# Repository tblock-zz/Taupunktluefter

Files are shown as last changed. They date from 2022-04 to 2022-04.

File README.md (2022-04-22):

Dies ist meine vereinfachte Version vom Taupunktlüfter der Maker Media GmbH.
Das Original mit den wichtigsten Fragen rund um den Taupunktlüfter beantwortet eine **[FAQ](https://heise.de/-6526328)**. Die vollständigen Artikel zum Projekt gibt es in der **[Make-Ausgabe 1/22 ab Seite 22](https://www.heise.de/select/make/2022/1/2135511212557842576)** und in der **[Make-Ausgabe 2/22 ab Seite 82](https://www.heise.de/select/make/2022/2/2204711461516715363)** zu lesen.

Das Original Github Projekt liegt hier: https://github.com/MakeMagazinDE/Taupunktluefter

# Taupunktlüfter

Der Zweig vom Original ist bewusst absolut einfach gehalten. Er besitzt nur noch eine vereinfachte Anzeige mit 2 LEDs. Rot für Fehler und grün für ordnungsgemäßen Betrieb. 

Allerdings habe ich die C++ Datei verändert. Einmal wird ein gleitender Mittelwert aus der Temperatur und der Luftfeuchtigkeit gebildet mit einer Probe alle 1s. 
Nach 5s wird dann die Taupunktberechnung ausgeführt und entsprechend das Relais geschaltet.

Der Code befindet sich im Verzeichnis TaupunktLueftungEinfach
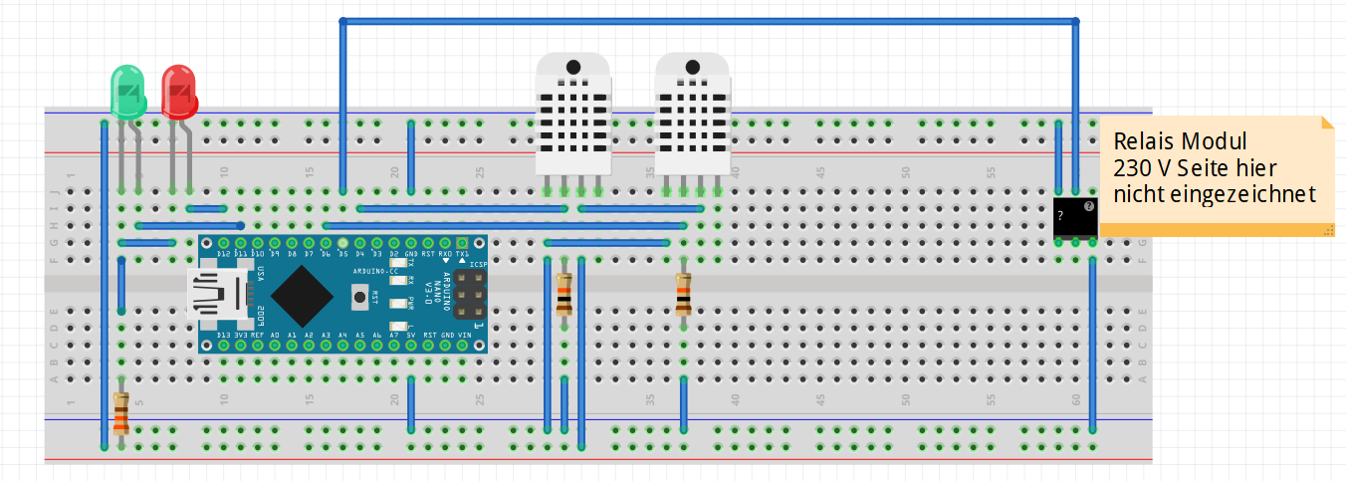
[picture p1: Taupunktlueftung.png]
Taupunktluefter

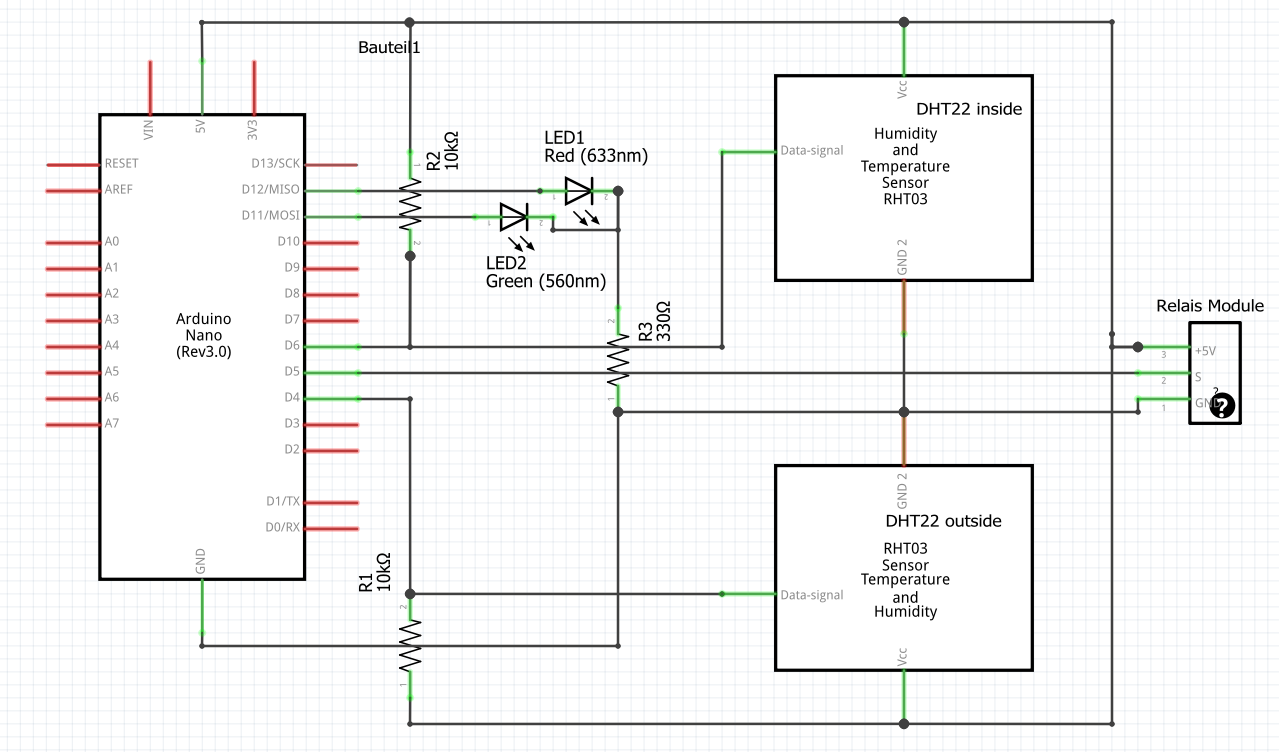
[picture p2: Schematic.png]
Schaltplan


Teileliste:
- 2 x Widerstand 10 kOhm
- 1 x Widerstand 330 Ohm
- 2 x DHT22
- 1 x Leuchtdiode rot
- 1 x Leuchtdiode grün
- 1 x Arduino Nano oder Arduino Uno etc.
- 1 x Relaismodul mit 5V Ansteuerung
- 1 x Lüfter 230 V

Im Programm werden die Bibliotheken DHT sensor library von Adafruit und Sodaq_wdt verwendet.

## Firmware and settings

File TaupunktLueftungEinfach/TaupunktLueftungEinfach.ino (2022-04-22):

/*
This code is without any warranty and without any liability of any kind.
Be aware that the FAN may use high voltage and it is your responsibility to understand that wrong usage may damage 
your life or your property.
*/
// These three libraries are necessary:
#include "DHT.h"       // DHT sensor library from Adafruit
#include <Wire.h> 
#include <avr/wdt.h>

//-------------------------------------------------------------------------------------------------------
#define PIN_RELAIS          5 // air venting relais control pin
#define PIN_DHT1            6 // data line inner DHT sensor
#define PIN_DHT2            4 // data line outer DHT sensor
#define PIN_LED_OK         11
#define PIN_LED_ERR        12

#define RELAIS_ON        HIGH
#define RELAIS_OFF        LOW

#define CORRECTION_T_1  -3.0f // correction value for inner temperature
#define CORRECTION_T_2  -4.0f // correction value for outer temperature
#define CORRECTION_H_1   0.0f // correction value for inner humidity
#define CORRECTION_H_2   0.0f // correction value for outer humidity

#define MIN_DEW          5.0f // minimal dew point difference for switching the relais
#define HYSTERESIS       1.0f // Distence for relais on/off switching
#define MIN_TEMP_1      14.0f // minimal inner temperature for activating the venting
#define MIN_TEMP_2     -10.0f // minimal outer temperature for activating the venting
//-------------------------------------------------------------------------------------------------------
typedef struct {
    float tmprt;              // temperatur
    float hmdty;              // humidity
} tData;

typedef struct {
    tData avrg;
    tData crctn;              // correction values
    float dp;                 // dew point
    DHT* pDht;                // pointer to the sensor object
} tFiltered;
//-------------------------------------------------------------------------------------------------------

DHT dht1(PIN_DHT1, DHT22);    // the inner sensor
DHT dht2(PIN_DHT2, DHT22);    // the outer sensor
tFiltered data[2];            // the data structure for the values for inner and outer sensor
bool relais, relaisState;

//-------------------------------------------------------------------------------------------------------
void initHmi()
{
  Serial.begin(115200);       // debugging output
  Serial.println(F("Testing sensors.."));
}

void printHmi(tFiltered& inner, tFiltered& outer, bool relaisOn)
{
  static const char txtSensor1[]     = "Sensor 1: ";
  static const char txtSensor2[]     = "Sensor 2: ";
  static const char txtHumidity[]    = "Humidity: ";
  static const char txtTemp[]        = "%  Temperature: ";
  static const char txtDewPoint[]    = "  Dew Point: ";
  static const char txtUnitCelsius[] = "°C  ";
    //  debugging output
#if 1
  Serial.print(txtSensor1);
  Serial.print(txtHumidity);
  Serial.print(inner.avrg.hmdty);                     
  Serial.print(txtTemp);
  Serial.print(inner.avrg.tmprt);
  Serial.print(txtUnitCelsius);
  Serial.print(txtDewPoint);
  Serial.print(inner.dp);
  Serial.println(txtUnitCelsius);

  Serial.print(txtSensor2);
  Serial.print(txtHumidity);
  Serial.print(outer.avrg.hmdty);
  Serial.print(txtTemp);
  Serial.print(outer.avrg.tmprt);
  Serial.print(txtUnitCelsius);
  Serial.print(txtDewPoint);
  Serial.print(outer.dp);
  Serial.println(txtUnitCelsius);
  Serial.print("Relais:"); Serial.println(relaisOn ? "ON" : "OFF");
  Serial.println();
#endif
}
//-------------------------------------------------------------------------------------------------------
void signalError()
{
  digitalWrite(PIN_LED_ERR, HIGH); 
  digitalWrite(PIN_LED_OK , LOW); 
  digitalWrite(PIN_RELAIS , RELAIS_OFF); 
  Serial.println("Error");
}

void signalOk()
{
  digitalWrite(PIN_LED_ERR, LOW); 
  digitalWrite(PIN_LED_OK , HIGH); 
}
//-------------------------------------------------------------------------------------------------------
float calcDewPoint(float t, float r) 
{ 
  float a, b;
  
  if (t >= 0.0f) {
    a =   7.5f;
    b = 237.3f;
  } 
  else if (t < 0.0f) {
    a =   7.6f;
    b = 240.7f;
  }
  
  // Saturated vapor pressure in hPa
  float svp = 6.1078f * pow(10.0f, (a*t)/(b+t));
  
  // Vapor pressure in hPa
  float vp = svp * (r/100.0f);
  
  // v-Parameter
  float v = log10(vp/6.1078f);
  
  // dew point temperature (°C)
  return (b*v) / (a-v);
}
//-------------------------------------------------------------------------------------------------------
void software_Reset() // restarts the program, but not the Sensors 
{
  asm volatile ("  jmp 0");  
}
//-------------------------------------------------------------------------------------------------------
void setup() {
  wdt_enable(WDTO_8S);                  // set watchdog timer to 8 seconds
  pinMode(PIN_RELAIS, OUTPUT);          
  digitalWrite(PIN_RELAIS, RELAIS_OFF); 

  pinMode(PIN_LED_OK, OUTPUT);       
  digitalWrite(PIN_LED_OK, LOW); 

  pinMode(PIN_LED_ERR, OUTPUT);       
  digitalWrite(PIN_LED_ERR, LOW); 

  initHmi();
      
  dht1.begin();                         // start sensors
  dht2.begin();   

  // initialize the data structure
  data[0].crctn.tmprt = CORRECTION_T_1;
  data[1].crctn.tmprt = CORRECTION_T_2;
  data[0].crctn.hmdty = CORRECTION_H_1;
  data[1].crctn.hmdty = CORRECTION_H_2;
  data[0].pDht = &dht1;
  data[1].pDht = &dht2;
  
  relaisState = false;
}
//-------------------------------------------------------------------------------------------------------
void waitForWatchdogReset()
{
  while(1);
}
//-------------------------------------------------------------------------------------------------------
bool isFastIntervalExceeded()
{
  static const uint32_t cInterval = 1000; // 1 second
  static       uint32_t last      = 0;
  
  uint32_t now = millis();
  bool     ret = (now >= last);
  if(ret) {
   last = now + cInterval;
  }
  return ret;
}

bool isSlowIntervalExceeded()
{
  static const uint32_t cInterval = 5000; // 5 seconds
  static       uint32_t last      = 0;
  
  uint32_t now = millis();
  bool     ret = (now >= last);
  if(ret) {
   last = now + cInterval;
  }
  return ret;
}
//-------------------------------------------------------------------------------------------------------
inline float calcMovingAverage(float x, float old)
{
  // calculate the moving average of the last 5 measurements
  return (4.0f*old + x)/5.0f;
}
//-------------------------------------------------------------------------------------------------------
void loop() 
{
  wdt_reset();                                         // Watchdog reset
  if(isFastIntervalExceeded()) {
    float h,t;
    for(auto i=0; i<2; ++i) {
      tFiltered& r = data[i];
      h = r.pDht->readHumidity();
      t = r.pDht->readTemperature();
      // Serial.println("\nh,t"); Serial.print(h); Serial.print(","); Serial.print(t);
      if(isnan(h) || isnan(t)) {
        signalError();
        waitForWatchdogReset();
      }
      else {
        signalOk();
        h += r.crctn.hmdty;
        t += r.crctn.tmprt;
        r.avrg.hmdty = calcMovingAverage(h, r.avrg.hmdty );
        r.avrg.tmprt = calcMovingAverage(t, r.avrg.tmprt );
      }
    }
  }

  if(isSlowIntervalExceeded()) {
    relais = false;
    for(auto i=0; i<2; ++i) {
      tFiltered& r = data[i];
      // becomes true when values are not allowed range
      relais = relais || (r.avrg.hmdty > 100.0f) || (r.avrg.hmdty < 1.0f);
      relais = relais || (r.avrg.tmprt < -40.0f) || (r.avrg.tmprt > 80.0f);
    }
    relais = !relais; // set relais when in allowed range
    if(relais) {
      for(auto i=0; i<2; ++i) {
        tFiltered& r = data[i];
        r.dp = calcDewPoint(r.avrg.tmprt, r.avrg.hmdty);
      }        
      float DeltaDp = data[0].dp - data[1].dp;

      // hysteresis calculation
      if(relaisState) {
        relais = (DeltaDp > MIN_DEW);
      }
      else {
        relais = (DeltaDp > (MIN_DEW + HYSTERESIS)); 
      }
      relais = relais && 
              (data[0].avrg.tmprt >= MIN_TEMP_1) &&
              (data[1].avrg.tmprt >= MIN_TEMP_2);
    }
    relaisState = relais;
    printHmi(data[0], data[1], relais);
    digitalWrite(PIN_RELAIS, relais ? RELAIS_ON : RELAIS_OFF);
  }
}

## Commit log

2022-04-01 First version, Schematics will follow
2022-04-01 added Fritzing file
    [taupunktluefterEinfach.fzz]
2022-04-07 update description with schematic
